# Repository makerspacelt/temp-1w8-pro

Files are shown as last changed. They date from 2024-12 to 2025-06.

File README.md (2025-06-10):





---
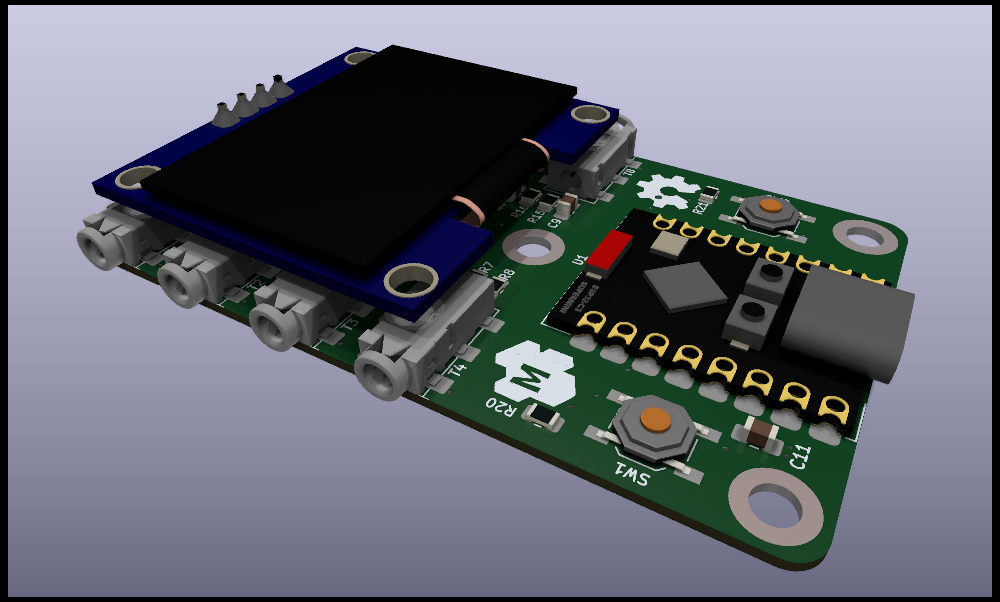
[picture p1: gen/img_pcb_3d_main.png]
PCB 3d main


This device is meant for temperature monitoring with up to 8 thermometers.

NOTE: This is only a prototype now, so things might not work and everything might change 

Basic target features:

* 8x 1-wire interfaces for DS18b20 using 2.5mm 4p audio jack connectors
* 2x user programmable buttons (can be used to wake up from deep sleep)
* 128x64 OLED display
* Powered via USB-C
* Compatibility with esphome and Home Assistant

Dev NOTE: before commit, run `./kibot.sh` to regenerate documentation, bom, gerbers and other assets.

* [schematics.pdf](gen/schematics.pdf)
* [pcb.pdf with dimensions](gen/pcb.pdf)
* [ibom.html](gen/single/ibom.html)

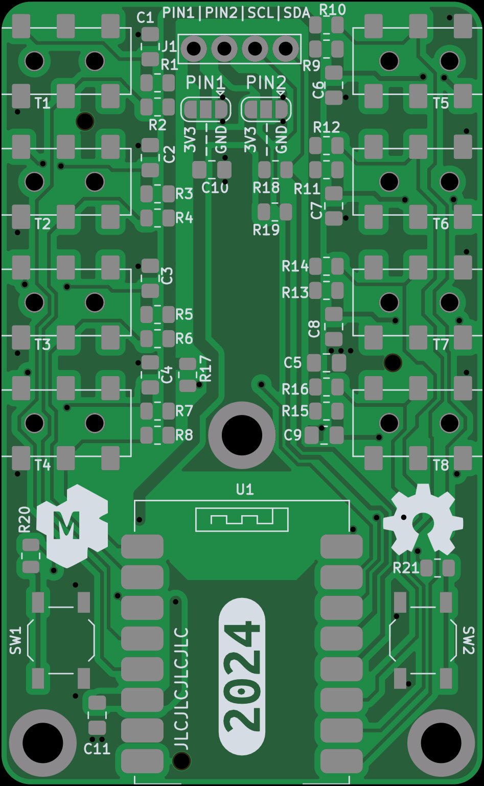
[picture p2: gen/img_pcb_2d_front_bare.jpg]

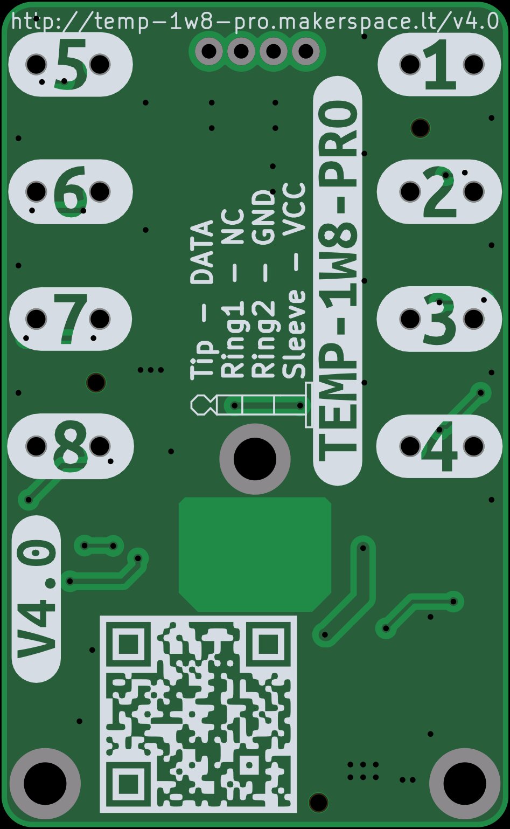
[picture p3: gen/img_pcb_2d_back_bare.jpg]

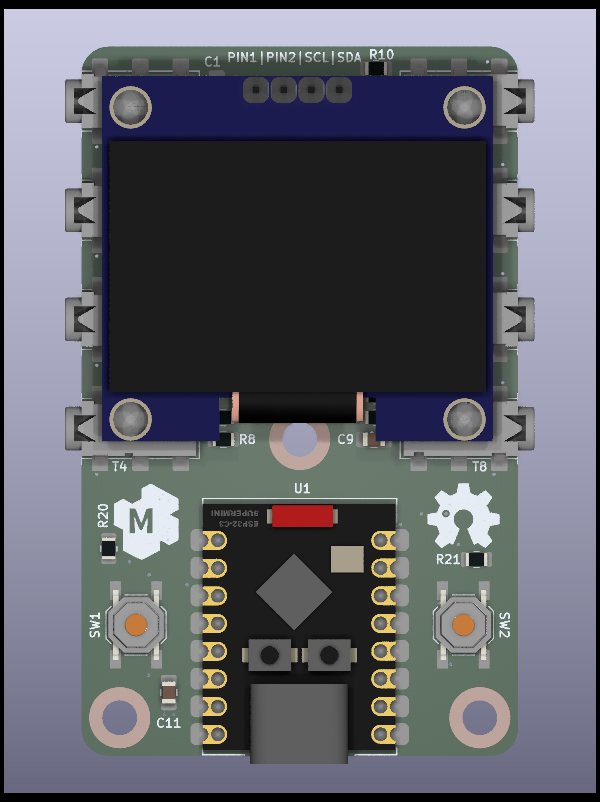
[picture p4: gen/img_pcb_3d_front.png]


---

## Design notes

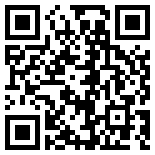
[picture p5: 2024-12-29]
gen/qr_link.png

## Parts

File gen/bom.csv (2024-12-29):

Row | Description | Part | References | Value | Footprint | Quantity Per PCB | Status | Datasheet | lcsc# | jlc-part-type
1 | Unpolarized capacitor | C | C1,C2,C3,C4,C6,C7,C8,C9 | 100n | C_0805_2012Metric_Pad1.18x1.45mm_HandSolder | 8 |  | ~ | C28233 | B
2 | Unpolarized capacitor | C | C5,C10,C11 | 10u | C_0805_2012Metric_Pad1.18x1.45mm_HandSolder | 3 |  | ~ | C15850 | B
3 | Generic connector, single row, 01x04, script generated (kicad-library-utils/schlib/autogen/connector/) | Conn_01x04 | J1 | ssd1306 oled | oled_i2c_1.3_128x64_ssd1306 | 1 |  | ~ |  | -
4 | Resistor | R | R17 | 100 | R_0805_2012Metric | 1 |  | ~ | C17408 | B
5 | Resistor | R | R1,R3,R5,R7,R9,R11,R13,R15,R20,R21 | 330 | R_0805_2012Metric | 10 |  | ~ | C17630 | B
6 | Resistor | R | R2,R4,R6,R8,R10,R12,R14,R16,R18,R19 | 4k7 | R_0805_2012Metric | 10 |  | ~ | C17673 | B
7 | Push button switch, generic, two pins | SW_Push | SW1,SW2 | USR_BTN | SW_SPST_TL3342 | 2 |  | https://jlcpcb.com/api/file/downloadByFileSystemAccessId/8550724022091735041 | C318884 | B
8 | Audio Jack, 4 Poles (Stereo / TRRS), Switched TR1 Poles (Normalling) | AudioJack4_SwitchTR1 | T1,T2,T3,T4,T5,T6,T7,T8 | PJ-242 | PJ-242 | 8 |  | https://www.lcsc.com/datasheet/lcsc_datasheet_2210081801_hanxia-HX-PJ-242_C5184834.pdf | C5184834 | E
9 |  | esp32-c3-supermini | U1 | esp32-c3-supermini | esp32-c3-supermini | 1 |  |  |  | -

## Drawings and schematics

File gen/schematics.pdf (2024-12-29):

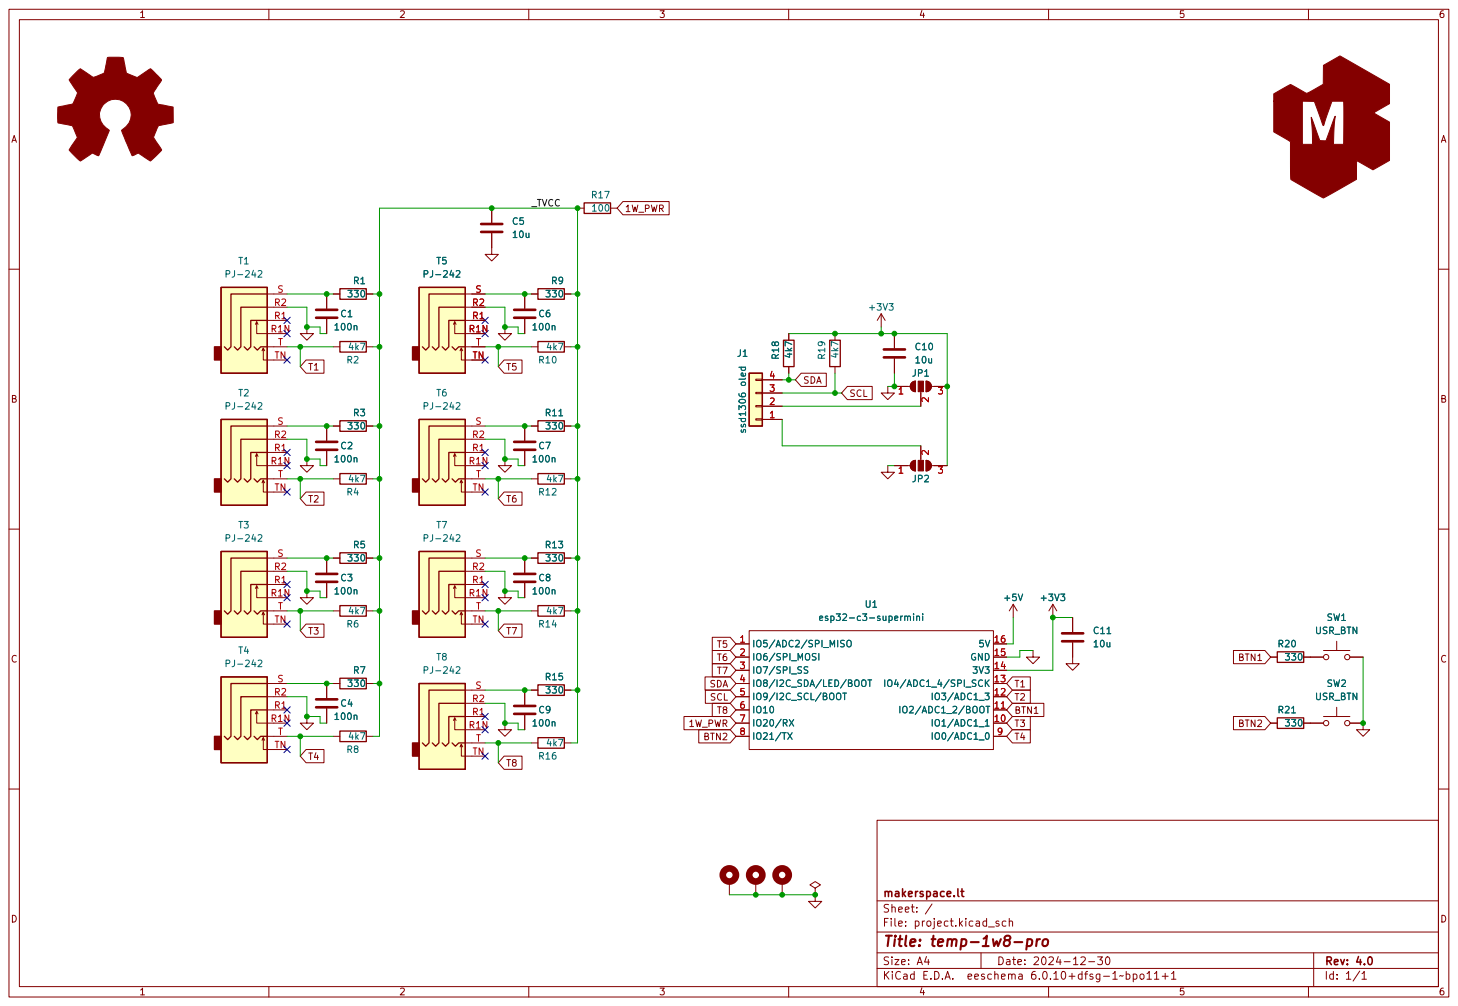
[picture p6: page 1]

Id: 1/1 Title: temp-1w8-pro

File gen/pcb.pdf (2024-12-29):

R9 C7

### PIN2

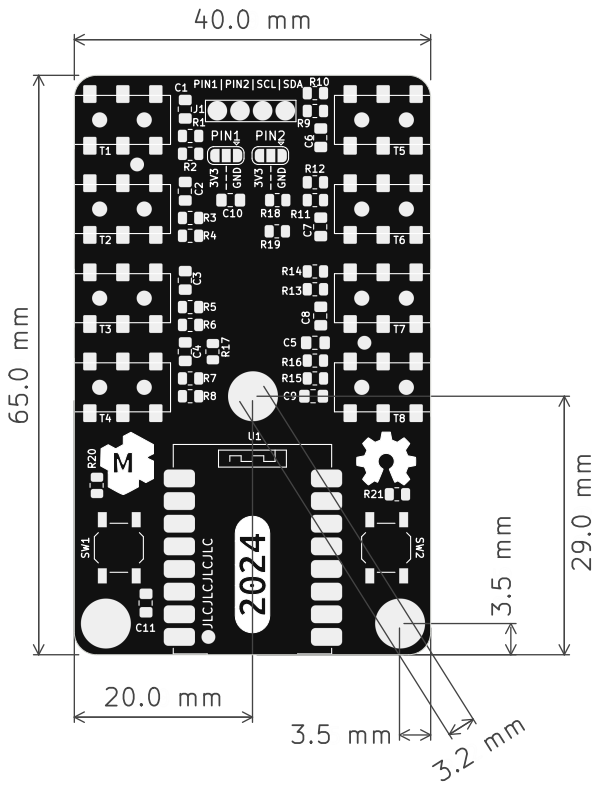
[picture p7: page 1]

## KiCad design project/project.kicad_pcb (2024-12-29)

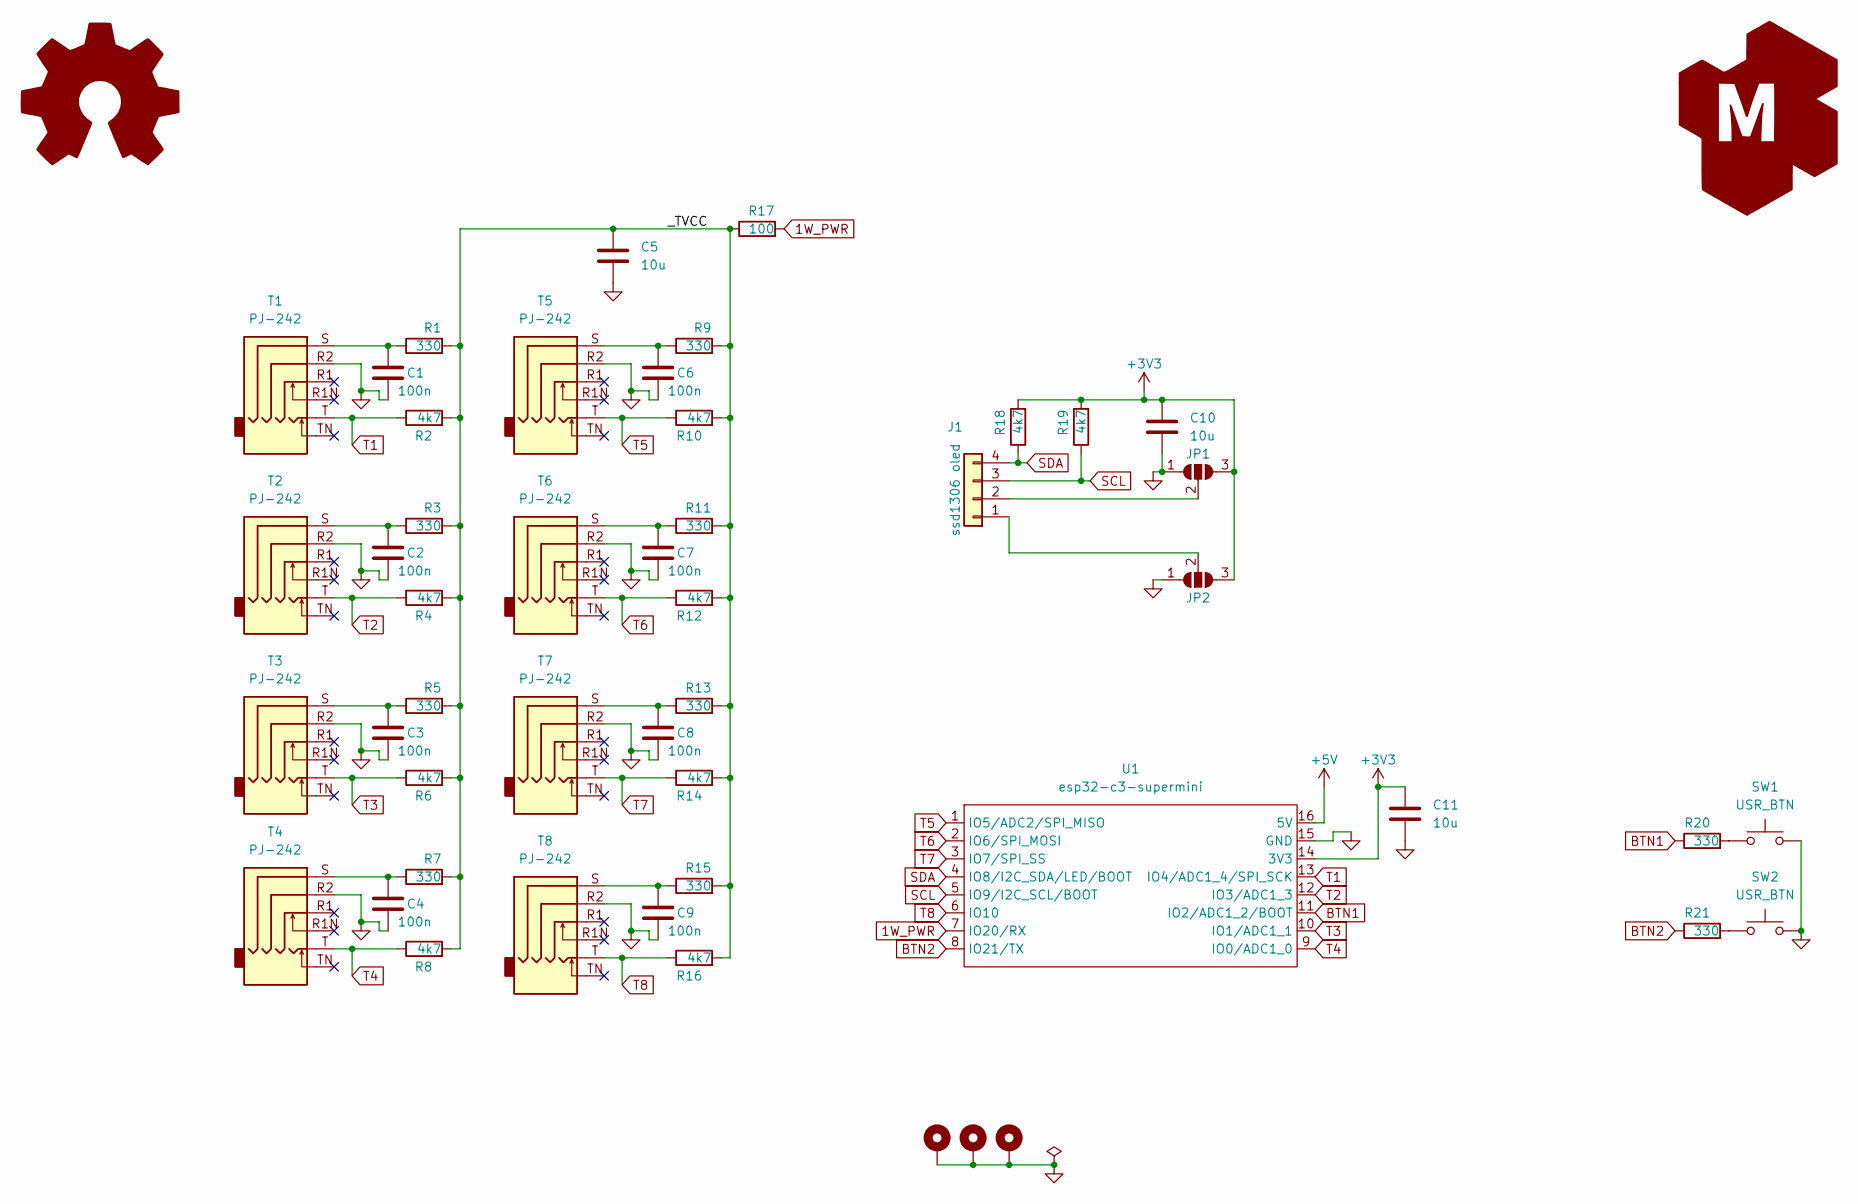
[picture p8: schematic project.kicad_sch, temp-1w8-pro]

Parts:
C1, C2, C3, C4, C6, C7, C8, C9: 100n; C_0805_2012Metric_Pad1.18x1.45mm_HandSolder; jlc-part-type B
C5, C10, C11: 10u; C_0805_2012Metric_Pad1.18x1.45mm_HandSolder; jlc-part-type B
G1: Logo_Open_Hardware_Large; OSHW-Symbol_6.7x6mm_SilkScreen
G2: LOGO_KMS; logo_kms_small_silkscreen
H1, H2, H3: MP; MountingHole_3.2mm_M3_DIN965_Pad
J1: ssd1306 oled; oled_i2c_1.3_128x64_ssd1306
JP1: PIN2; SolderJumper-3_P1.3mm_Open_RoundedPad1.0x1.5mm
JP2: PIN1; SolderJumper-3_P1.3mm_Open_RoundedPad1.0x1.5mm
R1, R3, R5, R7, R9, R11, R13, R15, R20, R21: 330; R_0805_2012Metric; jlc-part-type B
R2, R4, R6, R8, R10, R12, R14, R16, R18, R19: 4k7; R_0805_2012Metric; jlc-part-type B
R17: 100; R_0805_2012Metric; jlc-part-type B
SW1, SW2: USR_BTN; SW_SPST_TL3342; jlc-part-type B
T1, T2, T3, T4, T5, T6, T7, T8: PJ-242; lcsc# C5184834
U1: esp32-c3-supermini

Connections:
1W_PWR: R17.2, U1.7 (IO20/RX)
+3V3: C10.1, C11.1, JP1.3 (B), JP2.3 (B), R18.2, R19.2, U1.14 (3V3)
+5V: U1.16 (5V)
/_TVCC: C5.1, R1.2, R2.2, R3.2, R4.2, R5.2, R6.2, R7.2, R8.2, R9.2, R10.2, R11.2, R12.2, R13.2, R14.2, R15.2, R16.2, R17.1
BTN1: R20.1, U1.11 (IO2/ADC1_2/BOOT)
BTN2: R21.1, U1.8 (IO21/TX)
GND: C1.2, C2.2, C3.2, C4.2, C5.2, C6.2, C7.2, C8.2, C9.2, C10.2, C11.2, H1.1, H2.1, H3.1, JP1.1 (A), JP2.1 (A), SW1.2, SW2.2, T1.R2, T2.R2, T3.R2, T4.R2, T5.R2, T6.R2, T7.R2, T8.R2, U1.15 (GND)
unnamed: C1.1, R1.1, T1.S
unnamed: C2.1, R3.1, T2.S
unnamed: C3.1, R5.1, T3.S
unnamed: C4.1, R7.1, T4.S
unnamed: C6.1, R9.1, T5.S
unnamed: C7.1, R11.1, T6.S
unnamed: C8.1, R13.1, T7.S
unnamed: C9.1, R15.1, T8.S
unnamed: J1.1, JP2.2 (C)
unnamed: J1.2, JP1.2 (C)
unnamed: R20.2, SW1.1
unnamed: R21.2, SW2.1
SCL: J1.3, R19.1, U1.5 (IO9/I2C_SCL/BOOT)
SDA: J1.4, R18.1, U1.4 (IO8/I2C_SDA/LED/BOOT)
T1: R2.1, T1.T, U1.13 (IO4/ADC1_4/SPI_SCK)
T2: R4.1, T2.T, U1.12 (IO3/ADC1_3)
T3: R6.1, T3.T, U1.10 (IO1/ADC1_1)
T4: R8.1, T4.T, U1.9 (IO0/ADC1_0)
T5: R10.1, T5.T, U1.1 (IO5/ADC2/SPI_MISO)
T6: R12.1, T6.T, U1.2 (IO6/SPI_MOSI)
T7: R14.1, T7.T, U1.3 (IO7/SPI_SS)
T8: R16.1, T8.T, U1.6 (IO10)

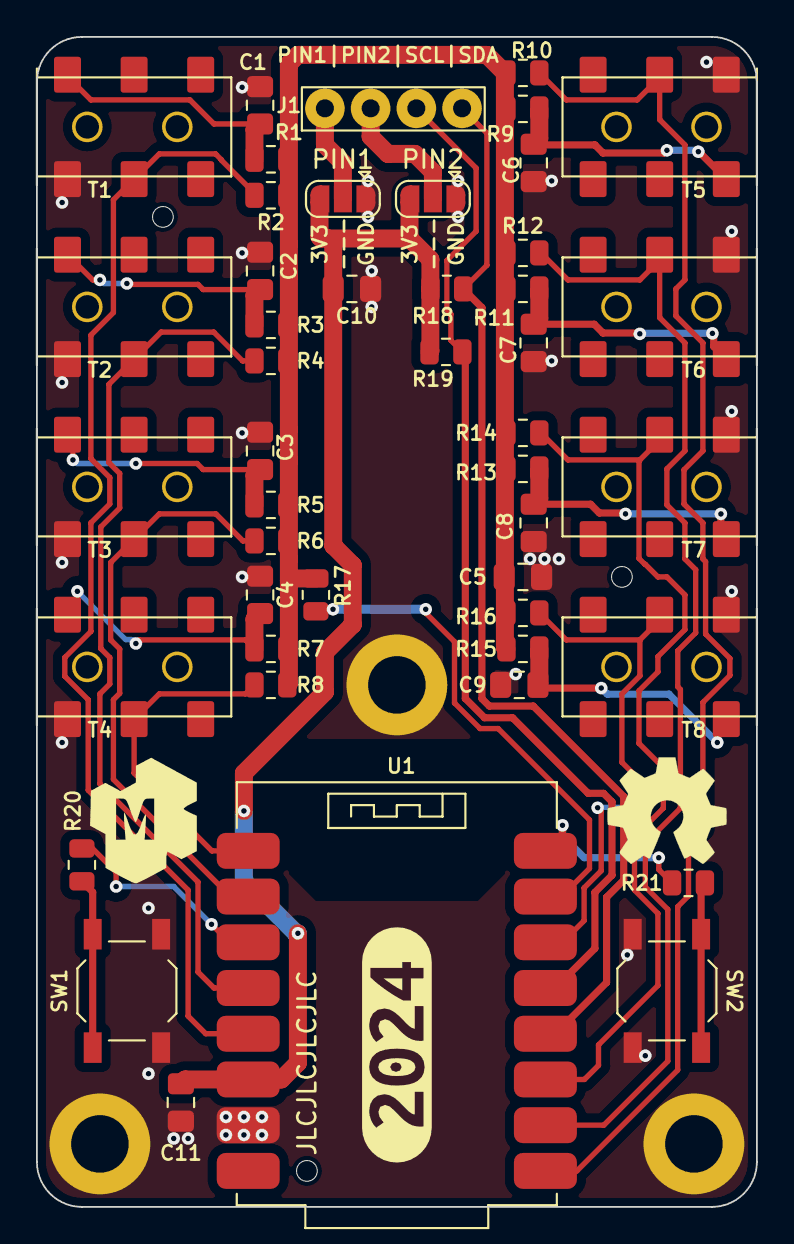
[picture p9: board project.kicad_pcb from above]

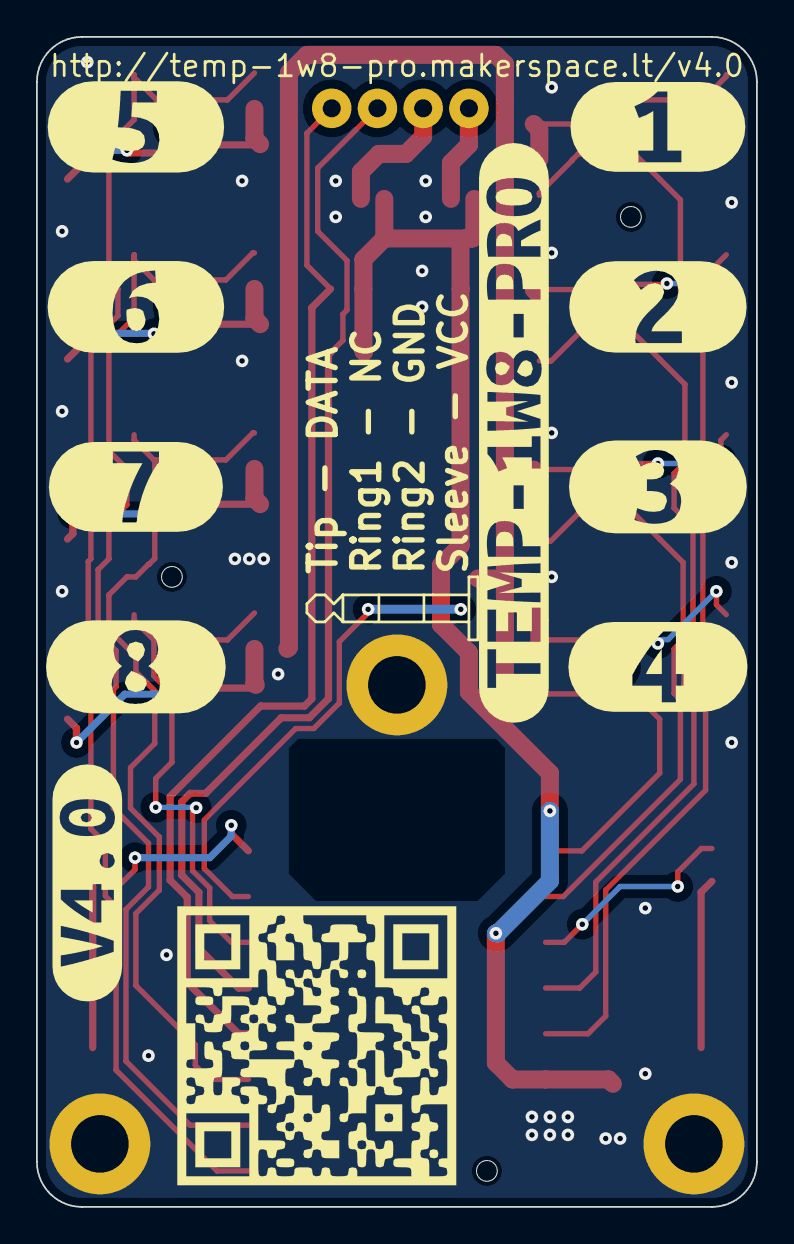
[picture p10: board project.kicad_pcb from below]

Board: 2 copper layers, 40.0 x 65.0 mm, 62 parts (10 on the bottom side), 28 nets.

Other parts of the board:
kibuzzard-66DA8205: G***; kibuzzard-66DA8205
kibuzzard-6769ACE8: G***; kibuzzard-6769ACE8
kibuzzard-6769ACFC: G***; kibuzzard-6769ACFC
kibuzzard-6769AD0A: G***; kibuzzard-6769AD0A
kibuzzard-6769AD2C: G***; kibuzzard-6769AD2C
kibuzzard-6769AD03: G***; kibuzzard-6769AD03
kibuzzard-6769AD10: G***; kibuzzard-6769AD10
kibuzzard-6769AD24: G***; kibuzzard-6769AD24
kibuzzard-6769B10C: G***; kibuzzard-6769B10C
kibuzzard-6771C807: G***; kibuzzard-6771C807
kibuzzard-669677F3: G***; kibuzzard-669677F3

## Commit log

2024-07-16 adding first prototype
    [_bom.csv, bom.csv, bom_lcsc.csv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]
2024-09-06 everything has changed
    [_bom.csv, bom.csv, bom_lcsc.csv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]
2024-09-12 adding link and qr code
    [project.kicad_pcb, project.kicad_sch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]
2024-09-15 updating bom and pnp positions
    [_bom.csv, bom.csv, bom_lcsc.csv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]
2024-10-10 fixed bugs from v1.0
    [_bom.csv, bom.csv, bom_lcsc.csv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]
2024-12-01 adding hard reset for sensors, removing rgb led
    [_bom.csv, bom.csv, bom_lcsc.csv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]
2024-12-23 numbering inputs, changing buttons, and adding tooling holes
    [_bom.csv, bom.csv, bom_lcsc.csv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]
2024-12-29 replacing power fet with resistor
    [_bom.csv, bom.csv, bom_lcsc.csv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]
2025-04-17 ESPHome yaml config with font that displays all sensors on screen at once.
2025-05-09 ID for i2c added.
2025-07-11 removing prototype notice
